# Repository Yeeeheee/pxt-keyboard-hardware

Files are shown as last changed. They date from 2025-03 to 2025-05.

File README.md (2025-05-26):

# pxt-keyboard

Micro:bit keyboard expansion<br>
Software: https://github.com/Yeeeheee/pxt-keyboard

## Schematic

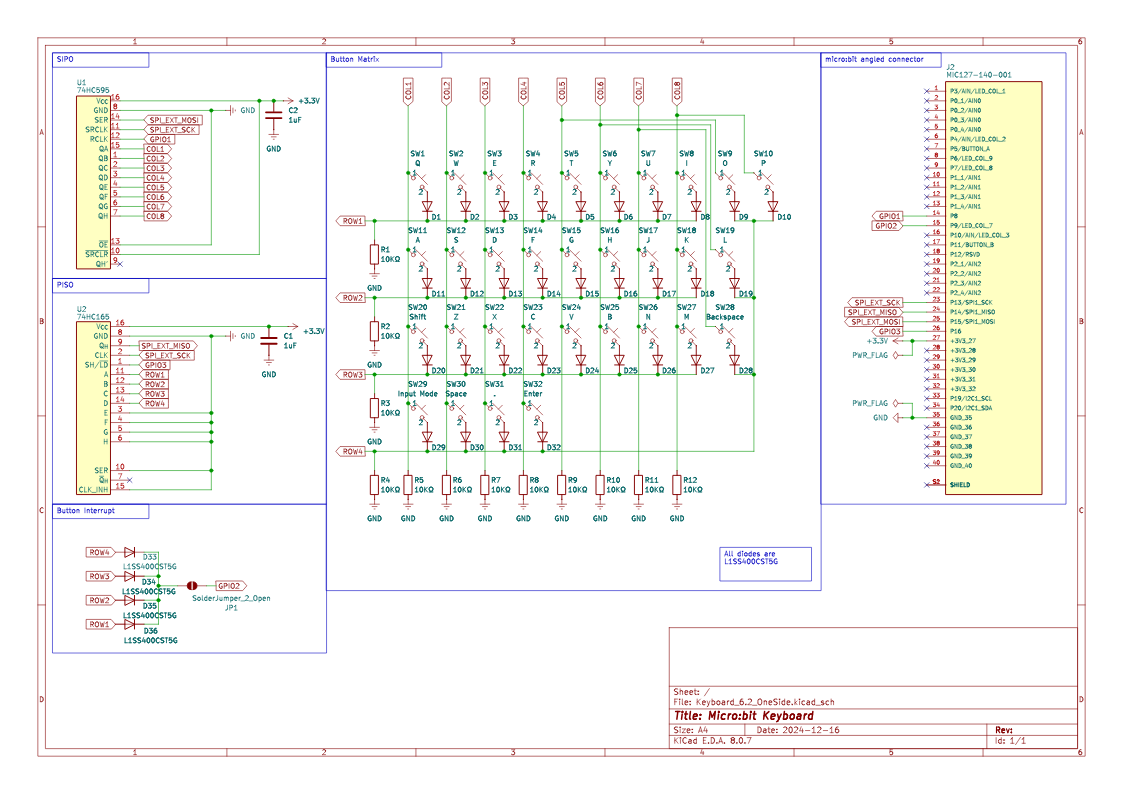
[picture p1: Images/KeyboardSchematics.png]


## Frontplate

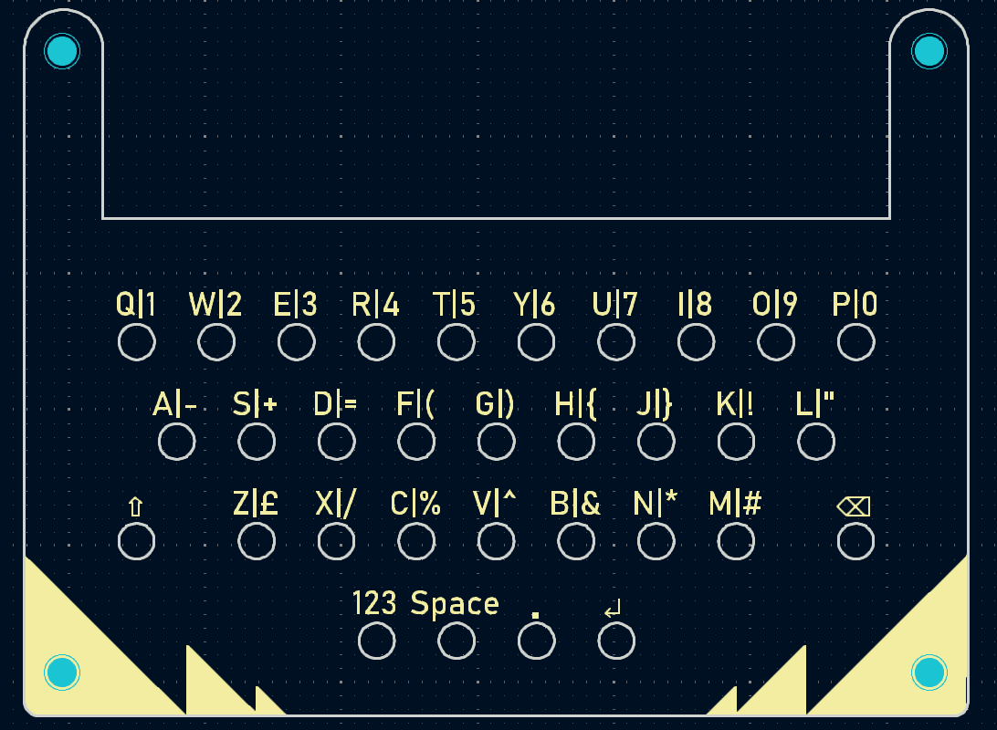
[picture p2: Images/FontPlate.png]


## License
MIT

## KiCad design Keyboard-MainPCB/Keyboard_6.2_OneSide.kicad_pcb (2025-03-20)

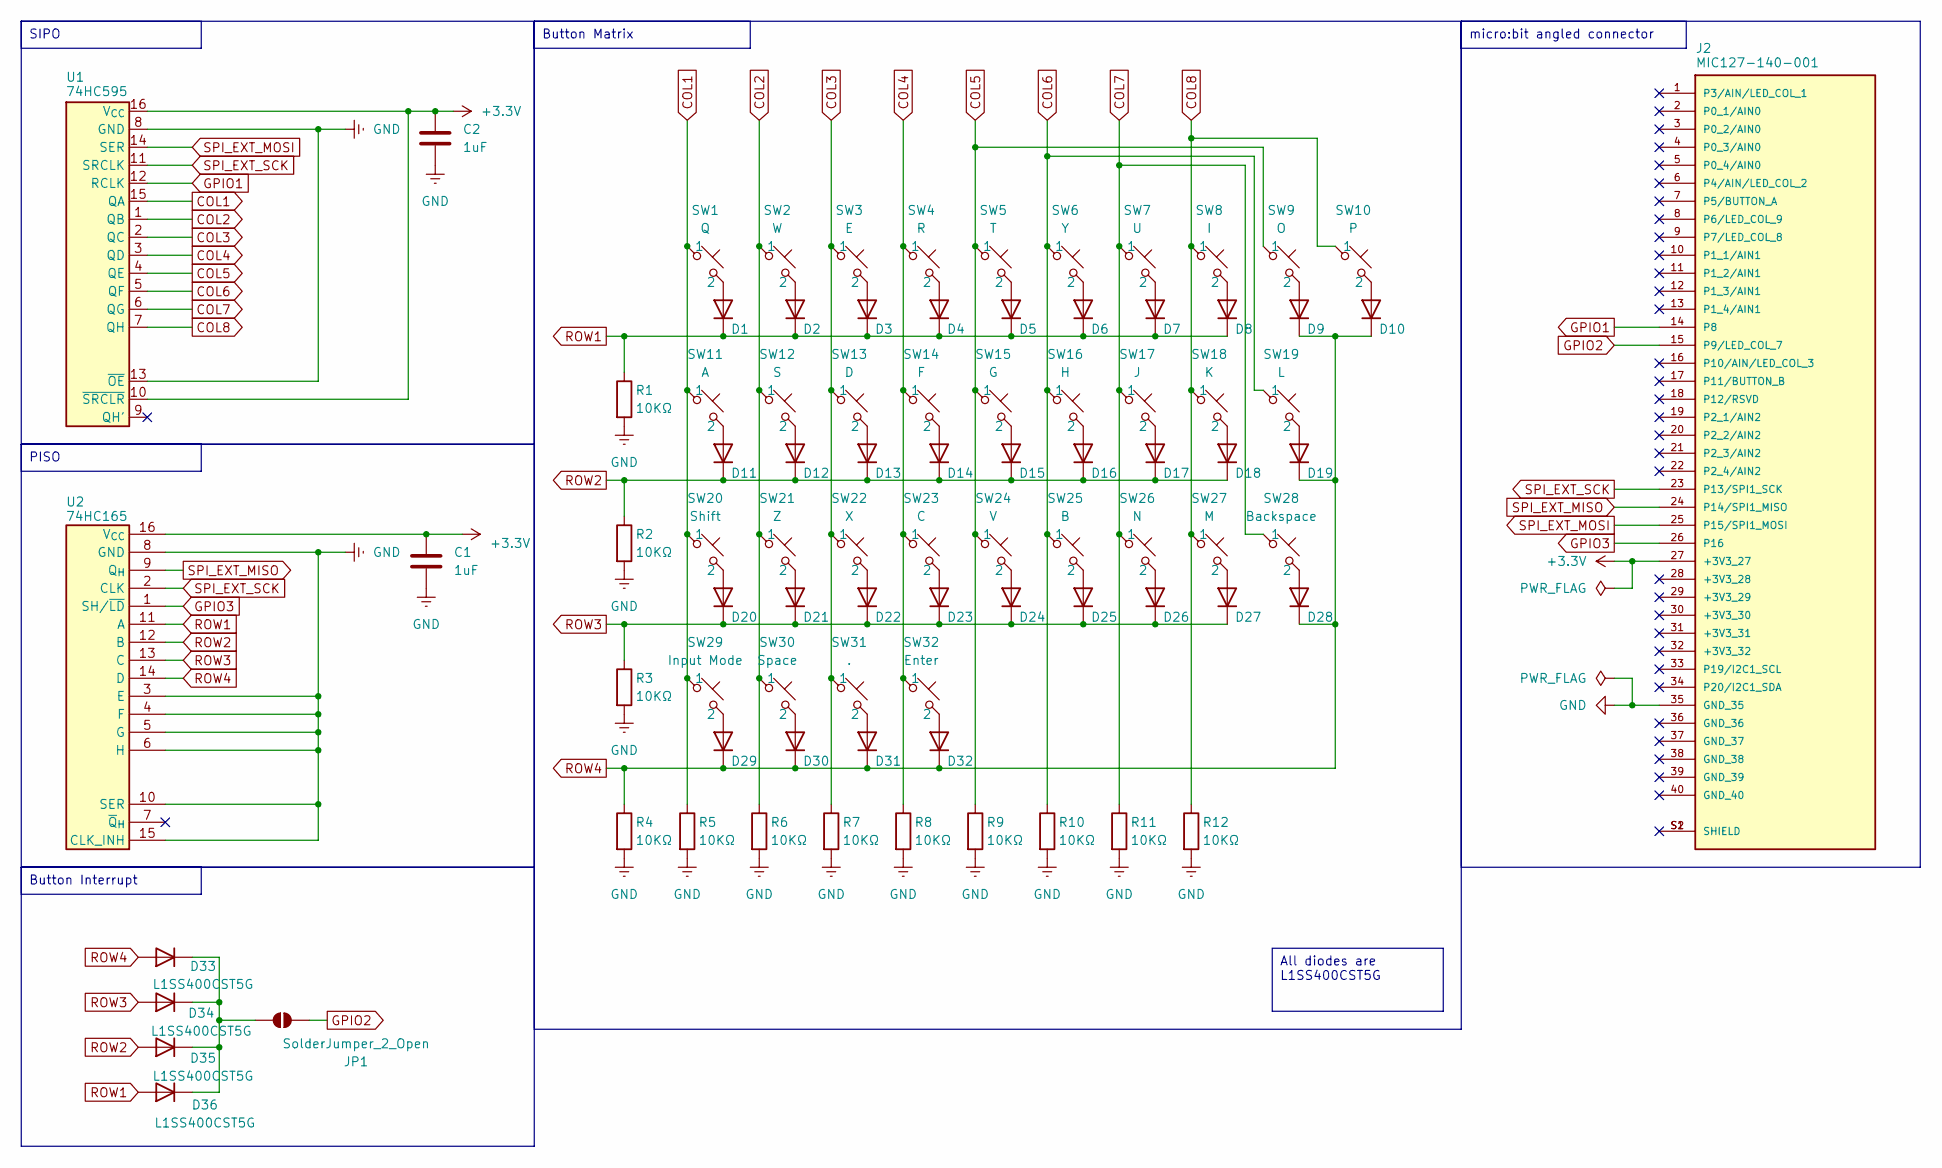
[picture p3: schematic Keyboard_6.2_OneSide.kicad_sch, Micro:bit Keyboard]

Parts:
C1, C2: 1uF; C_0603_1608Metric_Pad1.08x0.95mm_HandSolder; JLC part number C1592
D1, D2, D3, D4, D5, D6, D7, D8, D9, D10, D11, D12, D13, D14, D15, D16, D17, D18, D19, D20, D21, D22, D23, D24, D25, D26, D27, D28, D29, D30, D31, D32, D33, D34, D35, D36: L1SS400CST5G; D_SOD-923; JLC part number C383160
J2: MIC127-140-001; DONGGUAN_MIC127-140-001
JP1: SolderJumper_2_Open; SolderJumper-2_P1.3mm_Open_Pad1.0x1.5mm
R1, R2, R3, R4, R5, R6, R7, R8, R9, R10, R11, R12: 10KΩ; R_0402_1005Metric; JLC part number C25531
SW1: Q; KH-4.5X4.5X8H-STM; JLC part number C2837553
SW2: W; KH-4.5X4.5X8H-STM; JLC part number C2837553
SW3: E; KH-4.5X4.5X8H-STM; JLC part number C2837553
SW4: R; KH-4.5X4.5X8H-STM; JLC part number C2837553
SW5: T; KH-4.5X4.5X8H-STM; JLC part number C2837553
SW6: Y; KH-4.5X4.5X8H-STM; JLC part number C2837553
SW7: U; KH-4.5X4.5X8H-STM; JLC part number C2837553
SW8: I; KH-4.5X4.5X8H-STM; JLC part number C2837553
SW9: O; KH-4.5X4.5X8H-STM; JLC part number C2837553
SW10: P; KH-4.5X4.5X8H-STM; JLC part number C2837553
SW11: A; KH-4.5X4.5X8H-STM; JLC part number C2837553
SW12: S; KH-4.5X4.5X8H-STM; JLC part number C2837553
SW13: D; KH-4.5X4.5X8H-STM; JLC part number C2837553
SW14: F; KH-4.5X4.5X8H-STM; JLC part number C2837553
SW15: G; KH-4.5X4.5X8H-STM; JLC part number C2837553
SW16: H; KH-4.5X4.5X8H-STM; JLC part number C2837553
SW17: J; KH-4.5X4.5X8H-STM; JLC part number C2837553
SW18: K; KH-4.5X4.5X8H-STM; JLC part number C2837553
SW19: L; KH-4.5X4.5X8H-STM; JLC part number C2837553
SW20: Shift; KH-4.5X4.5X8H-STM; JLC part number C2837553
SW21: Z; KH-4.5X4.5X8H-STM; JLC part number C2837553
SW22: X; KH-4.5X4.5X8H-STM; JLC part number C2837553
SW23: C; KH-4.5X4.5X8H-STM; JLC part number C2837553
SW24: V; KH-4.5X4.5X8H-STM; JLC part number C2837553
SW25: B; KH-4.5X4.5X8H-STM; JLC part number C2837553
SW26: N; KH-4.5X4.5X8H-STM; JLC part number C2837553
SW27: M; KH-4.5X4.5X8H-STM; JLC part number C2837553
SW28: Backspace; KH-4.5X4.5X8H-STM; JLC part number C2837553
SW29: Input Mode; KH-4.5X4.5X8H-STM; JLC part number C2837553
SW30: Space; KH-4.5X4.5X8H-STM; JLC part number C2837553
SW31: .; KH-4.5X4.5X8H-STM; JLC part number C2837553
SW32: Enter; KH-4.5X4.5X8H-STM; JLC part number C2837553
U1: 74HC595; SOIC-16_3.9x9.9mm_P1.27mm; JLC part number C5947
U2: 74HC165; SOIC-16_3.9x9.9mm_P1.27mm; JLC part number C2863722

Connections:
+3.3V: C1.1, C2.1, J2.27 (+3V3_27), U1.10 (~SRCLR), U1.16 (V_{CC}), U2.16 (V_{CC})
COL1: R5.1, SW1.1, SW11.1, SW20.1, SW29.1, U1.15 (QA)
COL2: R6.1, SW2.1, SW12.1, SW21.1, SW30.1, U1.1 (QB)
COL3: R7.1, SW3.1, SW13.1, SW22.1, SW31.1, U1.2 (QC)
COL4: R8.1, SW4.1, SW14.1, SW23.1, SW32.1, U1.3 (QD)
COL5: R9.1, SW5.1, SW9.1, SW15.1, SW24.1, U1.4 (QE)
COL6: R10.1, SW6.1, SW16.1, SW19.1, SW25.1, U1.5 (QF)
COL7: R11.1, SW7.1, SW17.1, SW26.1, SW28.1, U1.6 (QG)
COL8: R12.1, SW8.1, SW10.1, SW18.1, SW27.1, U1.7 (QH)
GND: C1.2, C2.2, J2.35 (GND_35), R1.2, R2.2, R3.2, R4.2, R5.2, R6.2, R7.2, R8.2, R9.2, R10.2, R11.2, R12.2, U1.8 (GND), U1.13 (~OE), U2.3 (E), U2.4 (F), U2.5 (G), U2.6 (H), U2.8 (GND), U2.10 (SER), U2.15 (CLK_INH)
GPIO1: J2.14 (P8), U1.12 (RCLK)
GPIO2: J2.15 (P9/LED_COL_7), JP1.1 (A)
GPIO3: J2.26 (P16), U2.1 (SH/~LD)
unnamed: D1.2 (A), SW1.2
unnamed: D2.2 (A), SW2.2
unnamed: D3.2 (A), SW3.2
unnamed: D4.2 (A), SW4.2
unnamed: D5.2 (A), SW5.2
unnamed: D6.2 (A), SW6.2
unnamed: D7.2 (A), SW7.2
unnamed: D8.2 (A), SW8.2
unnamed: D9.2 (A), SW9.2
unnamed: D10.2 (A), SW10.2
unnamed: D11.2 (A), SW11.2
unnamed: D12.2 (A), SW12.2
unnamed: D13.2 (A), SW13.2
unnamed: D14.2 (A), SW14.2
unnamed: D15.2 (A), SW15.2
unnamed: D16.2 (A), SW16.2
unnamed: D17.2 (A), SW17.2
unnamed: D18.2 (A), SW18.2
unnamed: D19.2 (A), SW19.2
unnamed: D20.2 (A), SW20.2
unnamed: D21.2 (A), SW21.2
unnamed: D22.2 (A), SW22.2
unnamed: D23.2 (A), SW23.2
unnamed: D24.2 (A), SW24.2
unnamed: D25.2 (A), SW25.2
unnamed: D26.2 (A), SW26.2
unnamed: D27.2 (A), SW27.2
unnamed: D28.2 (A), SW28.2
unnamed: D29.2 (A), SW29.2
unnamed: D30.2 (A), SW30.2
unnamed: D31.2 (A), SW31.2
unnamed: D32.2 (A), SW32.2
unnamed: D33.1 (K), D34.1 (K), D35.1 (K), D36.1 (K), JP1.2 (B)
ROW1: D1.1 (K), D2.1 (K), D3.1 (K), D4.1 (K), D5.1 (K), D6.1 (K), D7.1 (K), D8.1 (K), D36.2 (A), R1.1, U2.11 (A)
ROW2: D11.1 (K), D12.1 (K), D13.1 (K), D14.1 (K), D15.1 (K), D16.1 (K), D17.1 (K), D18.1 (K), D35.2 (A), R2.1, U2.12 (B)
ROW3: D20.1 (K), D21.1 (K), D22.1 (K), D23.1 (K), D24.1 (K), D25.1 (K), D26.1 (K), D27.1 (K), D34.2 (A), R3.1, U2.13 (C)
ROW4: D9.1 (K), D10.1 (K), D19.1 (K), D28.1 (K), D29.1 (K), D30.1 (K), D31.1 (K), D32.1 (K), D33.2 (A), R4.1, U2.14 (D)
SPI_EXT_MISO: J2.24 (P14/SPI1_MISO), U2.9 (Q_{H})
SPI_EXT_MOSI: J2.25 (P15/SPI1_MOSI), U1.14 (SER)
SPI_EXT_SCK: J2.23 (P13/SPI1_SCK), U1.11 (SRCLK), U2.2 (CLK)

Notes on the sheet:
micro:bit angled connector
Button Matrix
Button Interrupt
All diodes are L1SS400CST5G
PISO
SIPO

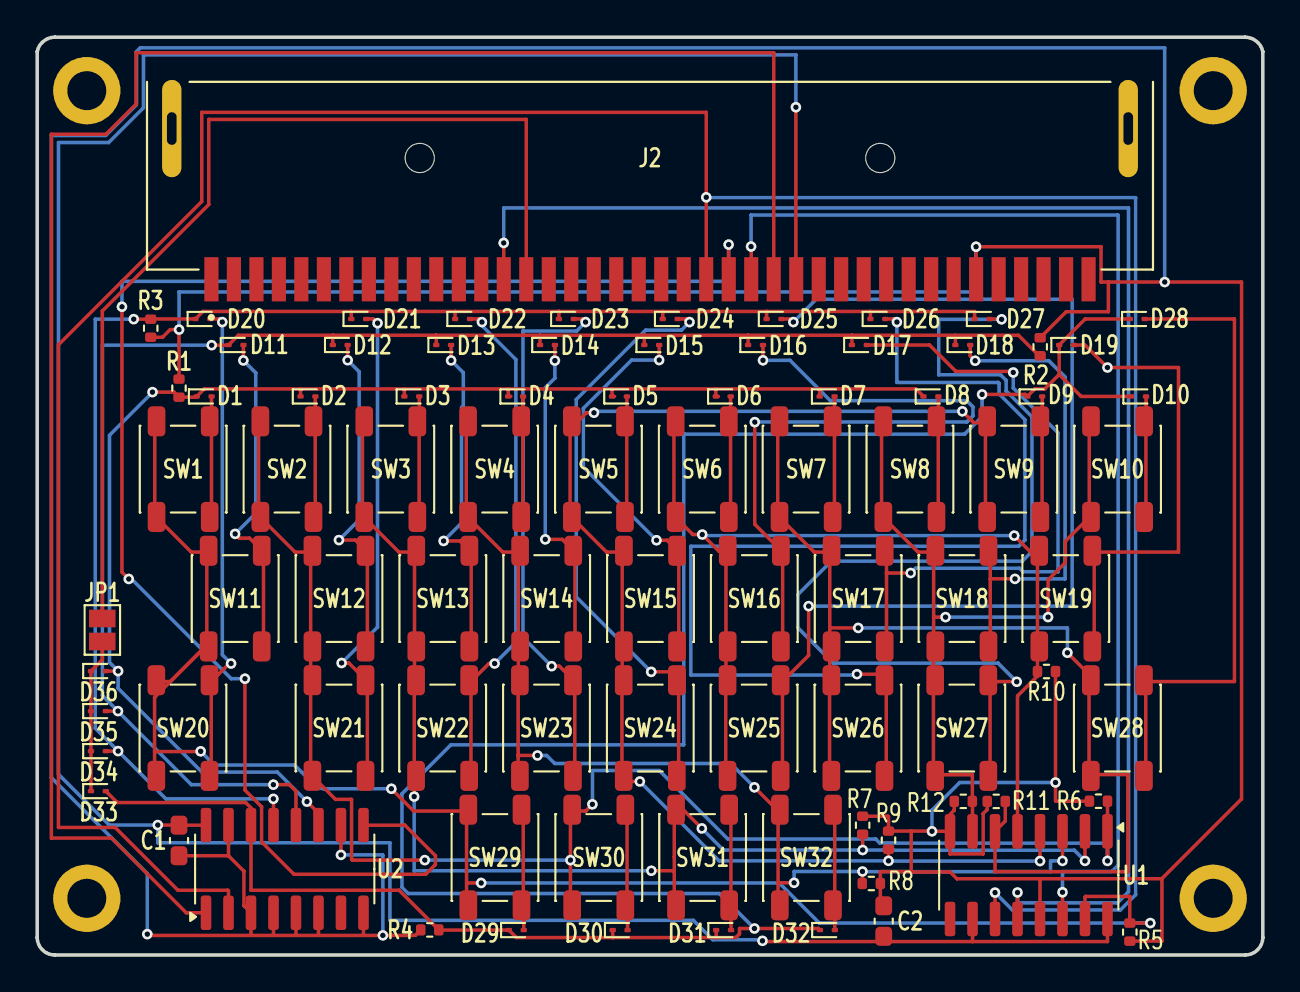
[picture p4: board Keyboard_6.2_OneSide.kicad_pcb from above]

Board: 2 copper layers, 69.2 x 51.8 mm, 86 parts (0 on the bottom side), 53 nets.
